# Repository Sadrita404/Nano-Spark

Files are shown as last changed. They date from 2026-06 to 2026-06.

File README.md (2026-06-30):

<div align="center">
  <table border="0" cellpadding="0" cellspacing="0">
    <tr>
      <td align="center" style="background: #ffffff; border: 1px solid #d0d7de; border-radius: 12px; padding: 16px; box-shadow: 0 4px 12px rgba(0,0,0,0.05);">
        Rough Layout For The PCB
        <div style="margin-top: 12px; font-family: -apple-system, BlinkMacSystemFont, 'Segoe UI', Helvetica, Arial, sans-serif; font-size: 13px; color: #57606a; font-weight: 500;">
      </td>
    </tr>
  </table>
</div>

| Title | Nano-Spark |
| :-- | :---|
|Author |Sadrita Neogi|

## What's this?
NanoSpark is an Digispark clone with All 6 GPIOs from the attiny available 5V output (direct from USB) 3V3 output (via AMS1117 voltage regulator) Power LED Onboard LED connected to PB1 USB-A connector

## Why I built it ?

To learn more about electronics and PCB design and also because the Digispark boards don't have a 3V3 output. This board also uses USB-A instead of Micro USB so I don't need any extra cable to connect to my laptop.

## Programming

The attiny chip needs to be flashed with a bootloader so that you can use it without a programmer (like an Arduino board). 
#### [Bootloader](https://github.com/Sadrita404/Nano-Spark/tree/main/Boot%20loader)

**[GUIDE](https://circuitdigest.com/microcontroller-projects/attiny85-ic-programming-through-usb-using-digispark-bootloader)**

These tutorials use the micronucleus bootloader used by the Digispark attiny boards.

There is an onboard LED hardwired to PB1 so you can get your blink sketch running without any extra hardware.

## Features

* All 6 GPIOs from the attiny available 

* 5V output (direct from USB)

* 3V3 output (via AMS1117 voltage regulator)

* Power LED

* Onboard LED connected to PB1

* USB-A connector

<div align="center">

| | PCB Designing | |
| :---: | :---: | :---: |
| Design 1 | Design 2 | Design 3 |
| Design 4 | Design 5 | Design 6 |

<div align="center">
  <h2> Final Look </h2>
  <table border="0" cellpadding="10" cellspacing="0" style="border-collapse: collapse;">
    <tr>
      <!-- FRONT SIDE CARD -->
      <td align="center" valign="top" width="50%" style="background: #ffffff; border: 1px solid #d0d7de; border-radius: 12px; padding: 16px; box-shadow: 0 4px 12px rgba(0,0,0,0.05);">
        Front Side View
        <div style="margin-top: 12px; font-family: -apple-system, BlinkMacSystemFont, 'Segoe UI', Helvetica, Arial, sans-serif; font-size: 13px; color: #57606a; font-weight: 600; text-transform: uppercase; letter-spacing: 0.5px;">
          ▲ Front Side View
        </div>
      </td>
      <!-- SPACER FOR GITHUB MOBILE DEGRADATION -->
      <td width="2%">&nbsp;</td>
      <!-- BACK SIDE CARD -->
      <td align="center" valign="top" width="50%" style="background: #ffffff; border: 1px solid #d0d7de; border-radius: 12px; padding: 16px; box-shadow: 0 4px 12px rgba(0,0,0,0.05);">
        Back Side View
        <div style="margin-top: 12px; font-family: -apple-system, BlinkMacSystemFont, 'Segoe UI', Helvetica, Arial, sans-serif; font-size: 13px; color: #57606a; font-weight: 600; text-transform: uppercase; letter-spacing: 0.5px;">
          ▲ Back Side View
        </div>
      </td>
    </tr>
  </table>
</div>
</div>

<div align="center">
  <h2> Bill of Materials </h2>
</div>

| Name | Purpose | Qty | Total (USD) | Link | Distributor |
| :--- | :--- | :---: | :---: | :---: | :--- |
| PCB Board | The main Board | 5 | 2.10 | [jlcpcb](https://jlcpcb.com) | jlcpcb |
| USB-A male connector (MOLEX 48037-0001) | For the connector | 10 | 0.95 | [flyrobo](https://www.flyrobo.in/usb-type-4-pin-male-connector-socket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) | flyrobo |
| Pin Headers (2x5) | For the connector | 5 | 0.24 | [robu](https://robu.in/product/1-month-warranty-921/) | robu |
| ATTINY13A-PU-MICROCHIP | The main chip | 3 | 5.71 | [robu](https://robu.in/product/attiny13a-pu-microchip-8-bit-mcu-low-power-high-performance-avr-attiny-family-attiny13-series-microcontrollers-avr/) | robu |
| 8 Pin DIP IC Socket Base Adaptor | For the chip | 5 | 0.26 | [robu](https://robu.in/product/8-pin-dip-ic-socket-base-adaptor-pack-of-10/) | robu |
| AMS1117 SMD voltage regulator | For Power control | 10 | 0.85 | [robu](https://robu.in/product/ams1117-3-3v-1a-sot-223-voltage-regulator-ic-pack-of-5-ics/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) | robu |
| 1k Ohm 0.5W (moq 10) | resistor (for USB) | 10 | 0.11 | [robu](https://robu.in/product/1k-ohm-0-5w-metal-film-resistor-pack-of-50/) | robu |
| 68Ω (moq 10) | resistor (for USB) | 10 | 0.12 | [robu](https://robu.in/product/68-ohm-1w-metal-film-resistor-pack-of-40/) | robu |
| SMD 1206 LED (moq 10 ) | The main led | 10 | 0.20 | [robu](https://robu.in/product/1206-surface-mount-led-orange-50-pcs/) | robu |
| 470Ω (moq 10) | For the leds | 10 | 0.11 | [robu](https://robu.in/product/470-ohm-0-25w-metal-film-resistor-pack-of-100/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) | robu |

<div align="center">
  <table border="0" cellpadding="0" cellspacing="0" style="border-collapse: collapse; max-width: 600px;">
    <tr>
      <td style="background: #ffffff; border: 1px solid #d0d7de; border-radius: 12px; padding: 20px; box-shadow: 0 4px 12px rgba(0,0,0,0.05); font-family: -apple-system, BlinkMacSystemFont, 'Segoe UI', Helvetica, Arial, sans-serif;">
        <div style="font-size: 16px; font-weight: 600; color: #24292f; margin-bottom: 12px; border-bottom: 1px solid #d0d7de; padding-bottom: 8px;">
           Final Summary Title
        </div>
        <table width="100%" border="0" style="border-collapse: collapse; font-size: 14px; color: #57606a;">
          <tr>
            <td style="padding: 4px 0;">Component Subtotal:</td>
            <td align="right" style="font-weight: 500; color: #24292f;">$10.65</td>
          </tr>
          <tr>
            <td style="padding: 4px 0;">Shipping Cost(incl. PCB):</td>
            <td align="right" style="font-weight: 500; color: #24292f;">$10.92</td>
          </tr>
          <tr>
            <td style="padding: 4px 0; padding-bottom: 8px;">Tax:</td>
            <td align="right" style="font-weight: 500; color: #24292f;">$1.5</td>
          </tr>
          <tr style="border-top: 1px dashed #d0d7de;">
            <td style="padding: 12px 0 0 0; font-weight: 600; color: #24292f; font-size: 15px;">Net Total Cost:</td>
            <td align="right" style="padding: 12px 0 0 0; font-weight: bold; color: #2da44e; font-size: 18px;">$23.07</td>
          </tr>
          <tr>
            <td style="padding: 2px 0 0 0; font-size: 11px; color: #8c959f;">Projected Budget Allocation:</td>
            <td align="right" style="padding: 2px 0 0 0; font-weight: 500; font-size: 12px; color: #8c959f;">$24</td>
          </tr>
        </table>
      </td>
    </tr>
  </table>
</div>

---
#### Please approve this project I have give my best in make the pcb design 

**Project Under Hack Club**

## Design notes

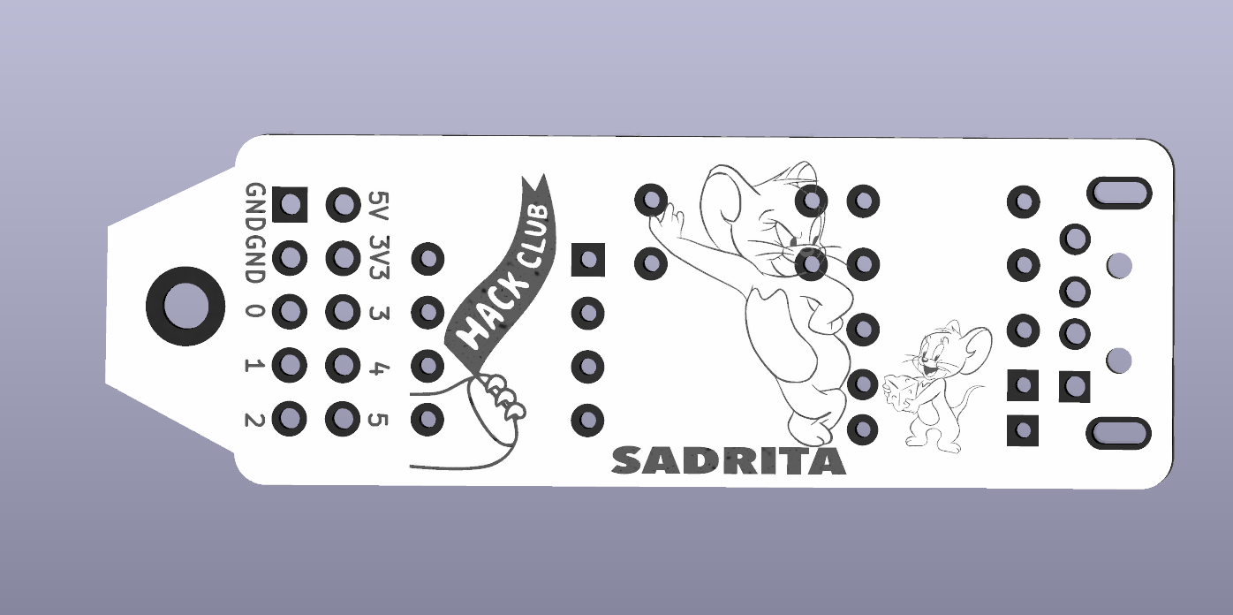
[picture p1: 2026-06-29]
Images/back.png

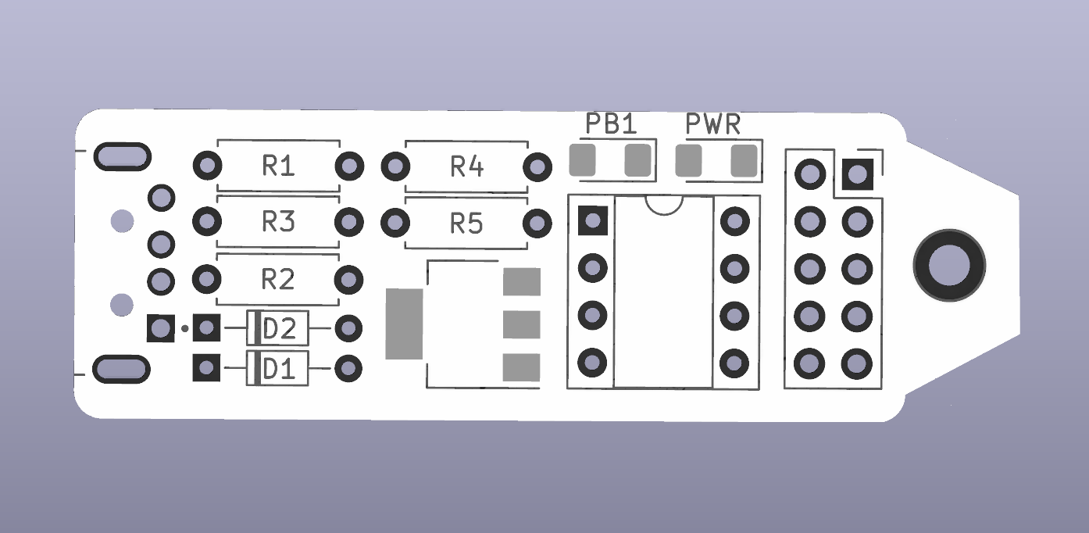
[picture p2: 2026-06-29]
Images/front.png

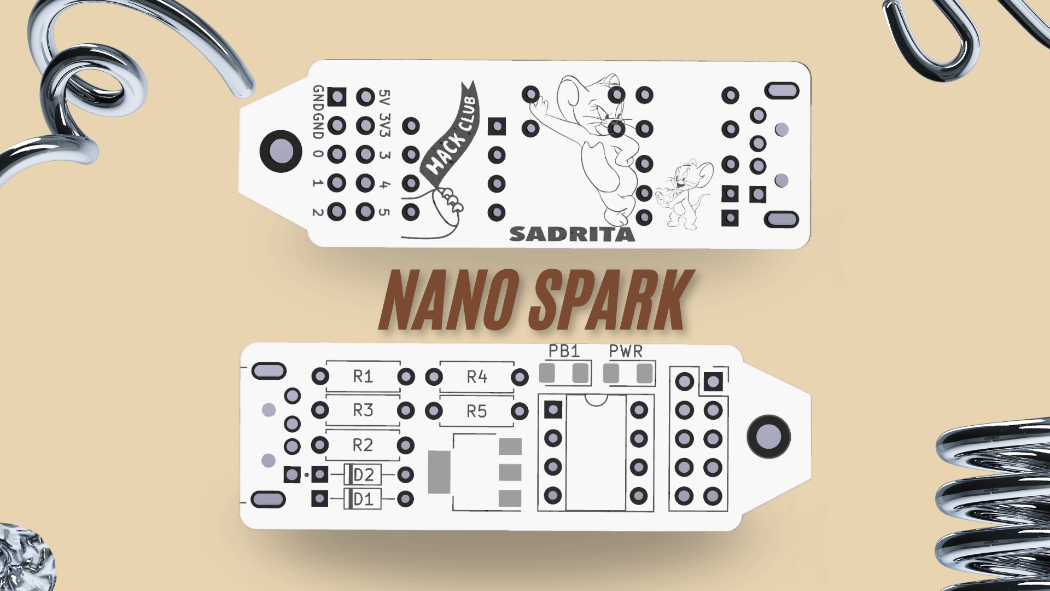
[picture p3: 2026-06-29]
Images/nano spark bannar.png

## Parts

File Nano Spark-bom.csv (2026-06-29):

Name | Purpose | Quantity | Total Cost (USD) | Link | Distributor
PCB Board | The main Board | 5 | 2.10 | https://jlcpcb.com | jlcpcb
USB-A male connector (MOLEX 48037-0001) | For the connector | 10 | 0.95 | https://www.flyrobo.in/usb-type-4-pin-male-connector-socket?tracking=ads | flyrobo
Pin Headers (2x5) | For the connector | 5 | 0.24 | https://robu.in/product/1-month-warranty-921/ | robu
ATTINY13A-PU-MICROCHIP | The main chip | 3 | 5.71 | https://robu.in/product/attiny13a-pu-microchip-8-bit-mcu-low-power-high-performance-avr-attiny-family-attiny13-series-microcontrollers-avr/ | robu
8 Pin DIP IC Socket Base Adaptor | For the chip | 5 | 0.26 | https://robu.in/product/8-pin-dip-ic-socket-base-adaptor-pack-of-10/ | robu
AMS1117 SMD voltage regulator | For Power control | 10 | 0.85 | https://robu.in/product/ams1117-3-3v-1a-sot-223-voltage-regulator-ic-pack-of-5-ics/?gad_source=1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 | robu
1k Ohm 0.5W (moq 10) | resistor (for USB) | 10 | 0.11 | https://robu.in/product/1k-ohm-0-5w-metal-film-resistor-pack-of-50/ | robu
68Ω (moq 10) | resistor (for USB) | 10 | 0.12 | https://robu.in/product/68-ohm-1w-metal-film-resistor-pack-of-40/ | robu
SMD 1206 LED (moq 10 ) | The main led | 10 | 0.20 | https://robu.in/product/1206-surface-mount-led-orange-50-pcs/ | robu
470Ω (moq 10) | For the leds | 10 | 0.11 | https://robu.in/product/470-ohm-0-25w-metal-film-resistor-pack-of-100/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 | robu

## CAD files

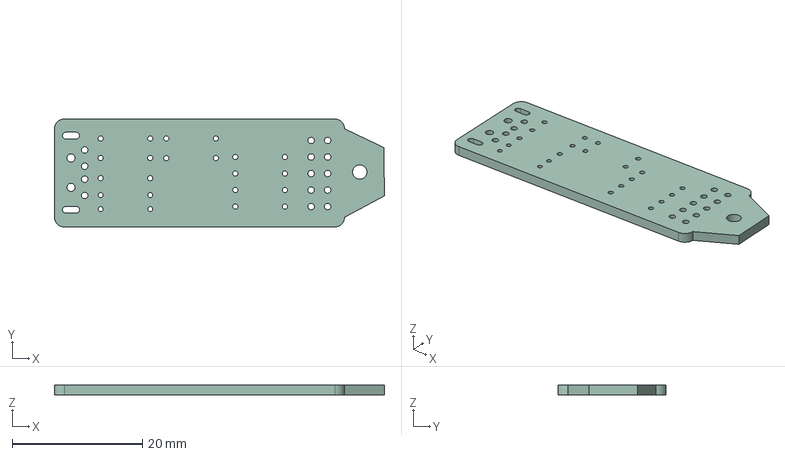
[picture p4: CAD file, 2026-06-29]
3d/Nano Spark.step
50.7 x 16.6 x 1.51 mm

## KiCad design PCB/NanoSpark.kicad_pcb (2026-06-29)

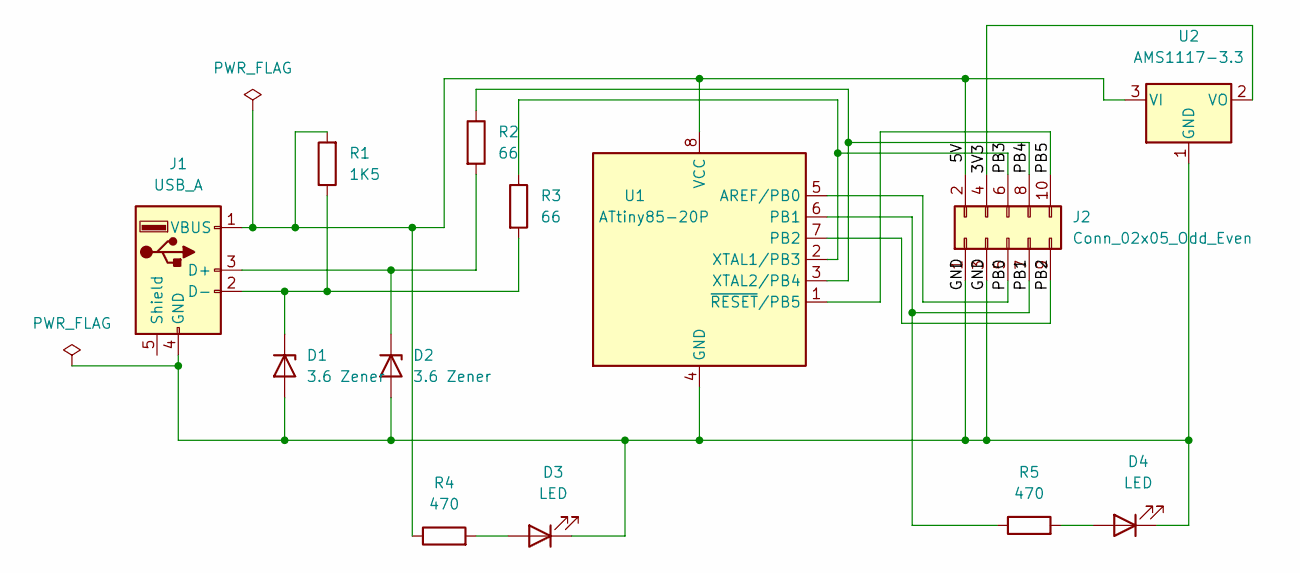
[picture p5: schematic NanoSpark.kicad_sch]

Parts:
D1, D2: 3.6 Zener; D_DO-34_SOD68_P7.62mm_Horizontal
D3, D4: LED; LED_1206_3216Metric_Pad1.42x1.75mm_HandSolder
J1: USB_A; MOLEX_48037-0001
J2: Conn_02x05_Odd_Even; PinSocket_2x05_P2.54mm_Vertical
R1: 1K5; R_Axial_DIN0207_L6.3mm_D2.5mm_P7.62mm_Horizontal
R2, R3: 66; R_Axial_DIN0207_L6.3mm_D2.5mm_P7.62mm_Horizontal
R4, R5: 470; R_Axial_DIN0207_L6.3mm_D2.5mm_P7.62mm_Horizontal
U1: ATtiny85-20P; DIP-8_W7.62mm_Socket
U2: AMS1117-3.3; SOT-223-3_TabPin2

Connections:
/3V3: J2.4, U2.2 (VO)
/5V: J1.1 (VBUS), J2.2, R1.2, R4.1, U1.8 (VCC), U2.3 (VI)
/GND: D1.2 (A), D2.2 (A), D3.1 (K), D4.1 (K), J1.4 (GND), J2.1, J2.3, U1.4 (GND), U2.1 (GND)
/PB0: J2.5, U1.5 (AREF/PB0)
/PB1: J2.7, R5.1, U1.6 (PB1)
/PB2: J2.9, U1.7 (PB2)
/PB3: J2.6, R3.1, U1.2 (XTAL1/PB3)
/PB4: J2.8, R2.1, U1.3 (XTAL2/PB4)
/PB5: J2.10, U1.1 (~RESET/PB5)
unnamed: D1.1 (K), J1.2 (D-), R1.1, R3.2
unnamed: D2.1 (K), J1.3 (D+), R2.2
unnamed: D3.2 (A), R4.2
unnamed: D4.2 (A), R5.2

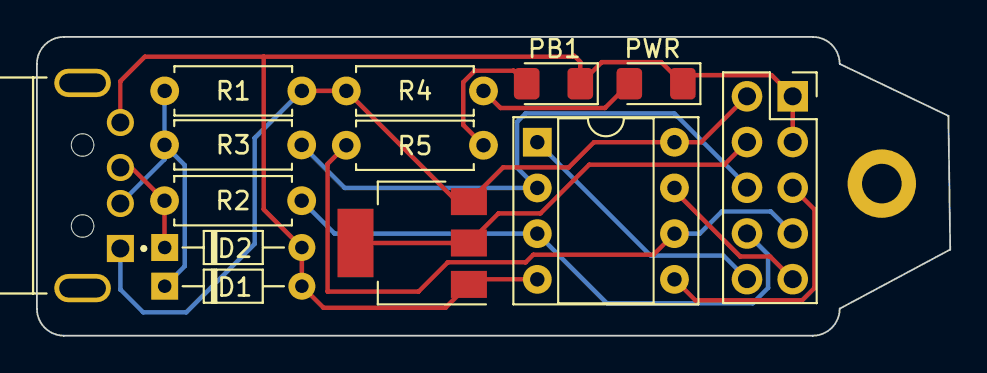
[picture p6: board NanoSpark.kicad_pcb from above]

Board: 2 copper layers, 50.7 x 16.6 mm, 13 parts (0 on the bottom side), 13 nets.

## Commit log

2026-06-29 gerber added
    [attiny85-B_Cu.gbl, attiny85-B_Mask.gbs, attiny85-B_Silkscreen.gbo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]
2026-06-29 BOM added
    [Nano Spark-bom.csv]
